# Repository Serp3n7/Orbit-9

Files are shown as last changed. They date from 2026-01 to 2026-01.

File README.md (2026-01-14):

# Orbit-9
**The Ultimate Macro-Controller for Developers & Designers**

  

---

## ⚡ Overview
**Orbit-9** is a workflow accelerator designed to replace repetitive keystrokes with single-tap efficiency. It combines a 3x3 mechanical grid with analog rotary control and a real-time OLED dashboard.

Whether you are snapping windows to multitask, controlling your media, or zooming through CAD models, Orbit-9 adapts to your workflow instantly.

## 💎 Key Features
* **Adaptive Intelligence:** 3 distinct layers (Navigation, Media, Design) that switch instantly via the encoder button.
* **Visual Feedback:** OLED display confirms your active mode and knob function.
* **Analog Control:** Precision rotary encoder for Volume, Brightness, and Zoom.
* **Window Management:** Dedicated layer for snapping windows and managing virtual desktops.
* **Developer Ready:** Native macros for VS Code, Git, and CAD tools.

---

## 🎛️ Workflow Modes

### 1. Navigator Mode (Default)
*The Multitasking Command Center.*
* **Knob:** `Volume Control`
* **Row 1:** `Desktop Left` • `Task View` • `Desktop Right`
* **Row 2:** `Snap Left` • `Maximize` • `Snap Right`
* **Row 3:** `Alt-Tab` • `Minimize` • `Screenshot`
* **Best For:** Managing multiple windows, splitting screens, and organizing your workspace.

### 2. Media Studio Mode
*The Entertainment Layer.*
* **Knob:** `Screen Brightness`
* **Keys:** Play, Pause, Next, Mute
* **Best For:** Spotify, YouTube, Background music control.

### 3. Design & Dev Mode (Pro)
*The Power User Suite.*
* **Knob:** `Zoom / Scroll` (Ctrl + Wheel)
* **Top Row:** `Undo` • `Copy` • `Paste`
* **Mid Row:** `Toggle Sidebar` • `Save` • `Command Palette`
* **Bot Row:** `Fit View (F6)` • `Format Code` • `Alt-Tab`

---

## 🛠️ Technical Specifications
| Spec | Detail |
| :--- | :--- |
| **Microcontroller** | Seeed Studio XIAO RP2040 |
| **Switch Matrix** | 3x3 (9 Keys) with Kailh Hotswap Sockets |
| **Display** | 0.96" OLED (SSD1306) |
| **Input Device** | EC11 Rotary Encoder |
| **Firmware** | KMK (CircuitPython) |

---

## 🚀 Quick Start
1.  **Flash:** Drag `CircuitPython.uf2` to the `RPI-RP2` drive.
2.  **Install:** Copy the `kmk` library folder to the `CIRCUITPY` drive.
3.  **Deploy:** Copy the `code.py` from this repo to the drive.
4.  **Use:** Click the knob to cycle modes.

---

## 🔌 Pinout Reference (Rev 1.0)
* **OLED:** `D4` (SDA), `D5` (SCL)
* **Encoder:** `D0`, `D1` (Rotation), `D10` (Switch)
* **Matrix Cols:** `D2`, `D3`, `D6`
* **Matrix Rows:** `D7`, `D8`, `D9`

---

## 📦 Bill of Materials
* 1x Seeed XIAO RP2040
* 1x Orbit-9 PCB
* 9x Kailh MX Hotswap Sockets
* 9x 1N4148 Diodes
* 1x EC11 Rotary Encoder
* 1x SSD1306 OLED Display
* 9x Mechanical Switches & Keycaps

---

## 📄 License
**Orbit-9** is Open Source Hardware.
* **Firmware:** MIT License
* **Hardware Design:** CERN-OHL-W

*Designed with ❤️ by [Sumit Patil]*

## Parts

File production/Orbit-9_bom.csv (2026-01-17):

Designator | Footprint | Quantity | Value | LCSC Part #
D1, D10, D2, D3, D4, D5, D6, D7, D8, D9 | Diode_SOD-123 | 10 | ~
H1, H2, H3, H4 | MountingHole_2.2mm_M2_DIN965_Pad | 4 | ~
J1 | PinSocket_1x04_P2.54mm_Vertical | 1 | Conn_01x04
R1, R2 | 0805 | 2 | R
S1, S2, S3, S4, S5, S6, S7, S8, S9 | Hotswap_MX_1.00u | 9 | ~
SW1 | RotaryEncoder_Alps_EC11E-Switch_Vertical_H20mm | 1 | RotaryEncoder_Switch
U1 | Seeed_XIAO_RP2040 | 1 | MCU_Seeed_XIAO_RP2040

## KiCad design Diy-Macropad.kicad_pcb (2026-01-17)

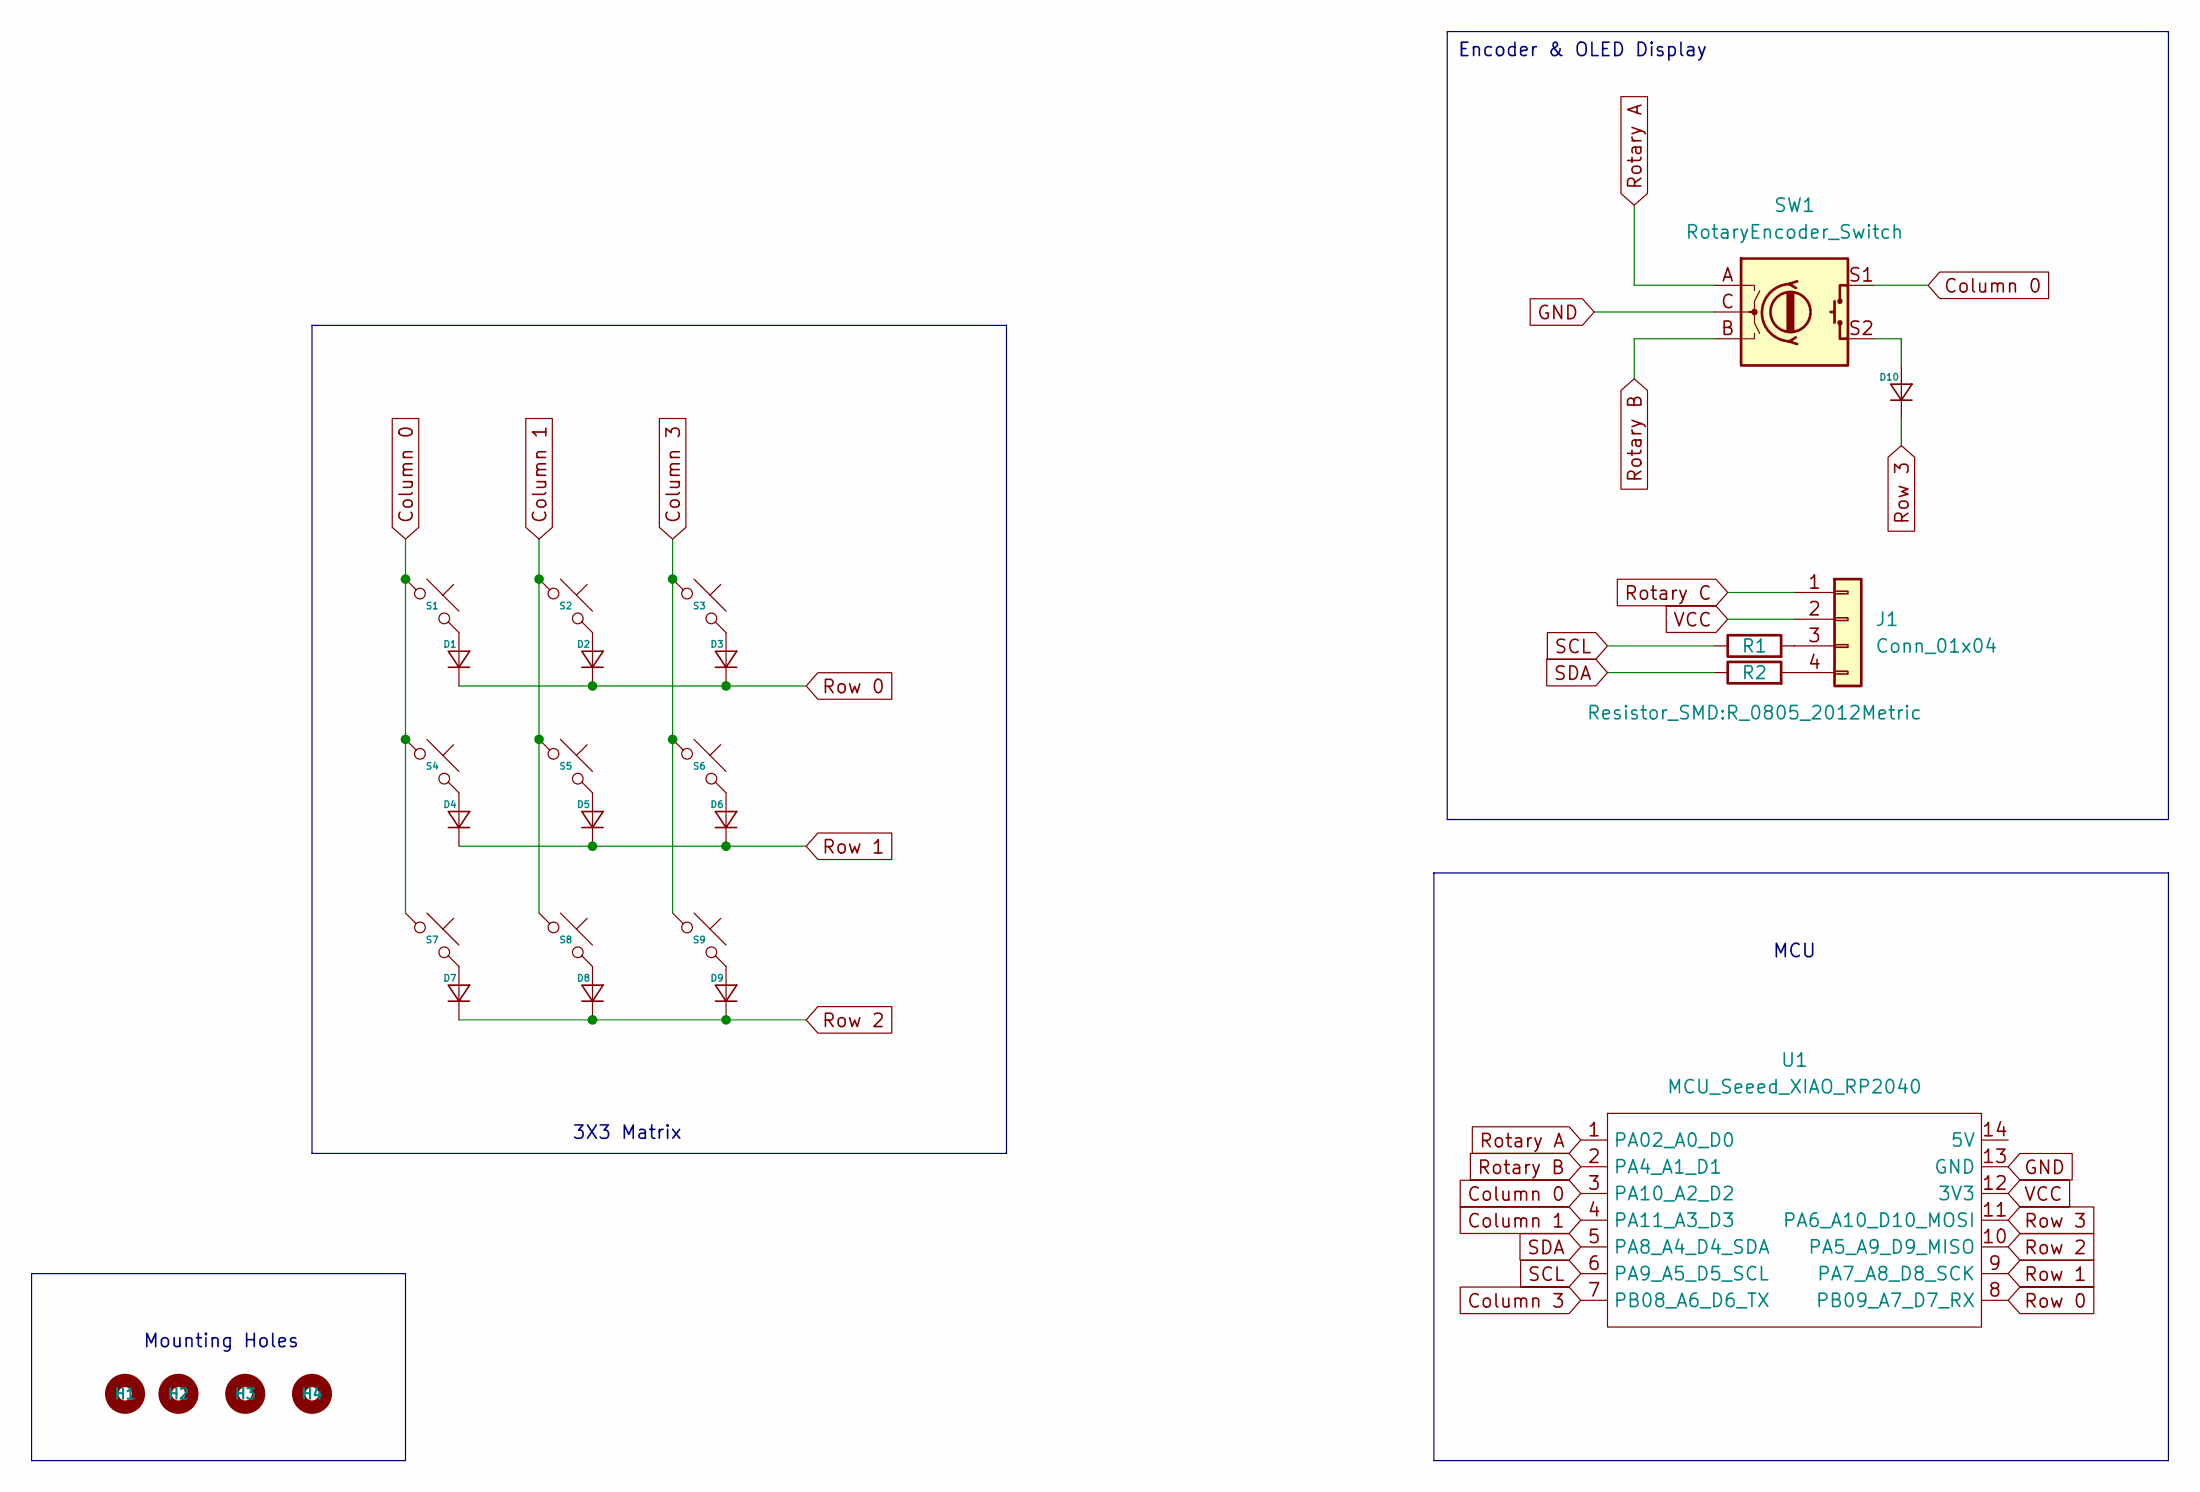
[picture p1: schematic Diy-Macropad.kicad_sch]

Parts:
D1, D2, D3, D4, D5, D6, D7, D8, D9, D10: Diode_SOD-123
H1, H2, H3, H4: MountingHole_2.2mm_M2_DIN965_Pad
J1: Conn_01x04; PinSocket_1x04_P2.54mm_Vertical
R1, R2: R; R_0805_2012Metric
S1, S2, S3, S4, S5, S6, S7, S8, S9: Hotswap_MX_1.00u
SW1: RotaryEncoder_Switch; RotaryEncoder_Alps_EC11E-Switch_Vertical_H20mm
U1: MCU_Seeed_XIAO_RP2040; Seeed_XIAO_RP2040

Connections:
Column 0: S1.1, S4.1, S7.1, SW1.S1, U1.3 (PA10_A2_D2)
Column 1: S2.1, S5.1, S8.1, U1.4 (PA11_A3_D3)
Column 3: S3.1, S6.1, S9.1, U1.7 (PB08_A6_D6_TX)
GND: SW1.C, U1.13 (GND)
unnamed: D1.2 (A), S1.2
unnamed: D2.2 (A), S2.2
unnamed: D3.2 (A), S3.2
unnamed: D4.2 (A), S4.2
unnamed: D5.2 (A), S5.2
unnamed: D6.2 (A), S6.2
unnamed: D7.2 (A), S7.2
unnamed: D8.2 (A), S8.2
unnamed: D9.2 (A), S9.2
unnamed: D10.2 (A), SW1.S2
unnamed: J1.3, R1.2
unnamed: J1.4, R2.2
Rotary A: SW1.A, U1.1 (PA02_A0_D0)
Rotary B: SW1.B, U1.2 (PA4_A1_D1)
Rotary C: J1.1
Row 0: D1.1 (K), D2.1 (K), D3.1 (K), U1.8 (PB09_A7_D7_RX)
Row 1: D4.1 (K), D5.1 (K), D6.1 (K), U1.9 (PA7_A8_D8_SCK)
Row 2: D7.1 (K), D8.1 (K), D9.1 (K), U1.10 (PA5_A9_D9_MISO)
Row 3: D10.1 (K), U1.11 (PA6_A10_D10_MOSI)
SCL: R1.1, U1.6 (PA9_A5_D5_SCL)
SDA: R2.1, U1.5 (PA8_A4_D4_SDA)
VCC: J1.2, U1.12 (3V3)

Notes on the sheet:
3X3 Matrix
Mounting Holes
MCU
Encoder & OLED Display

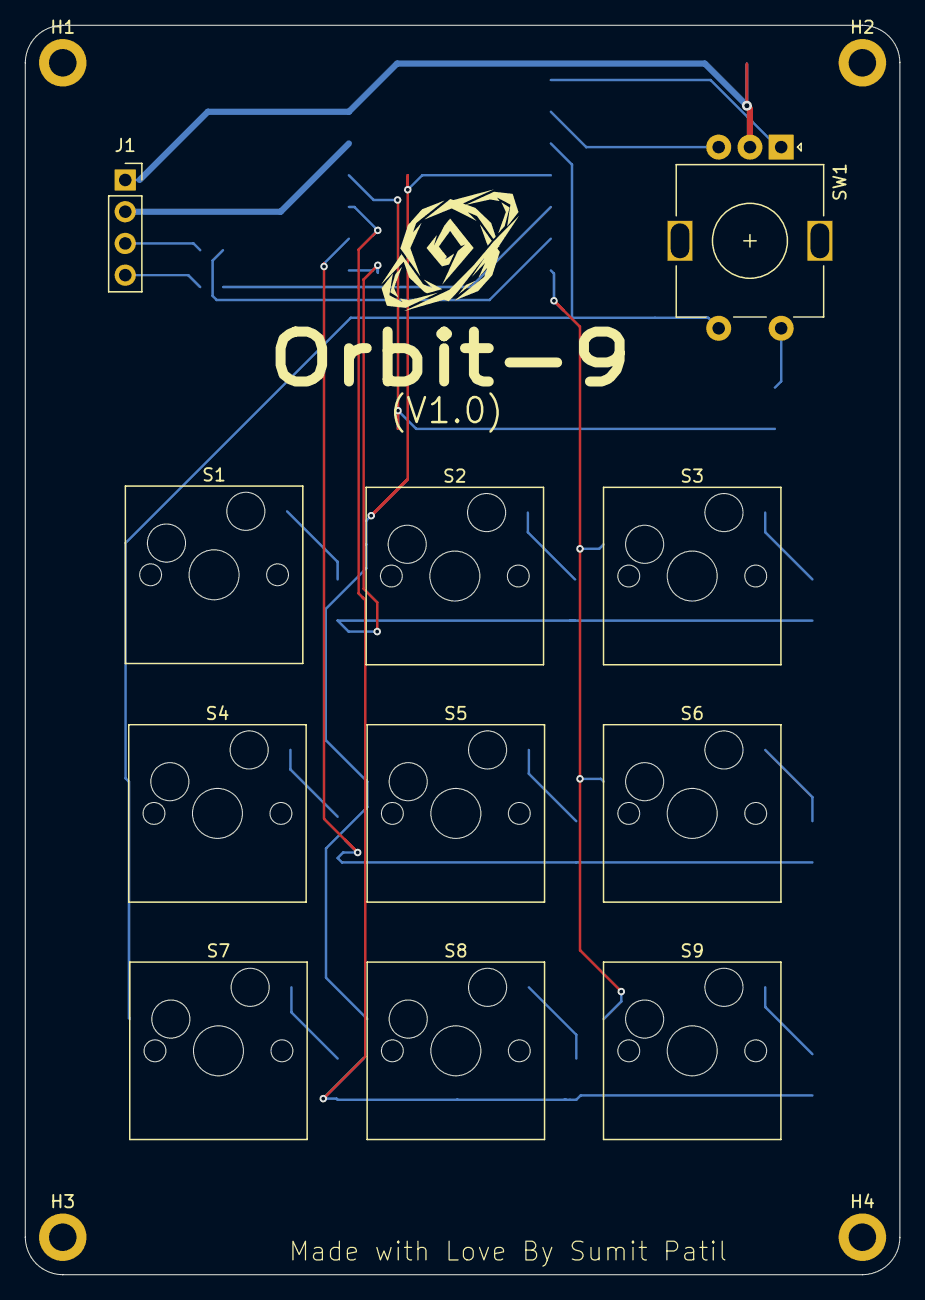
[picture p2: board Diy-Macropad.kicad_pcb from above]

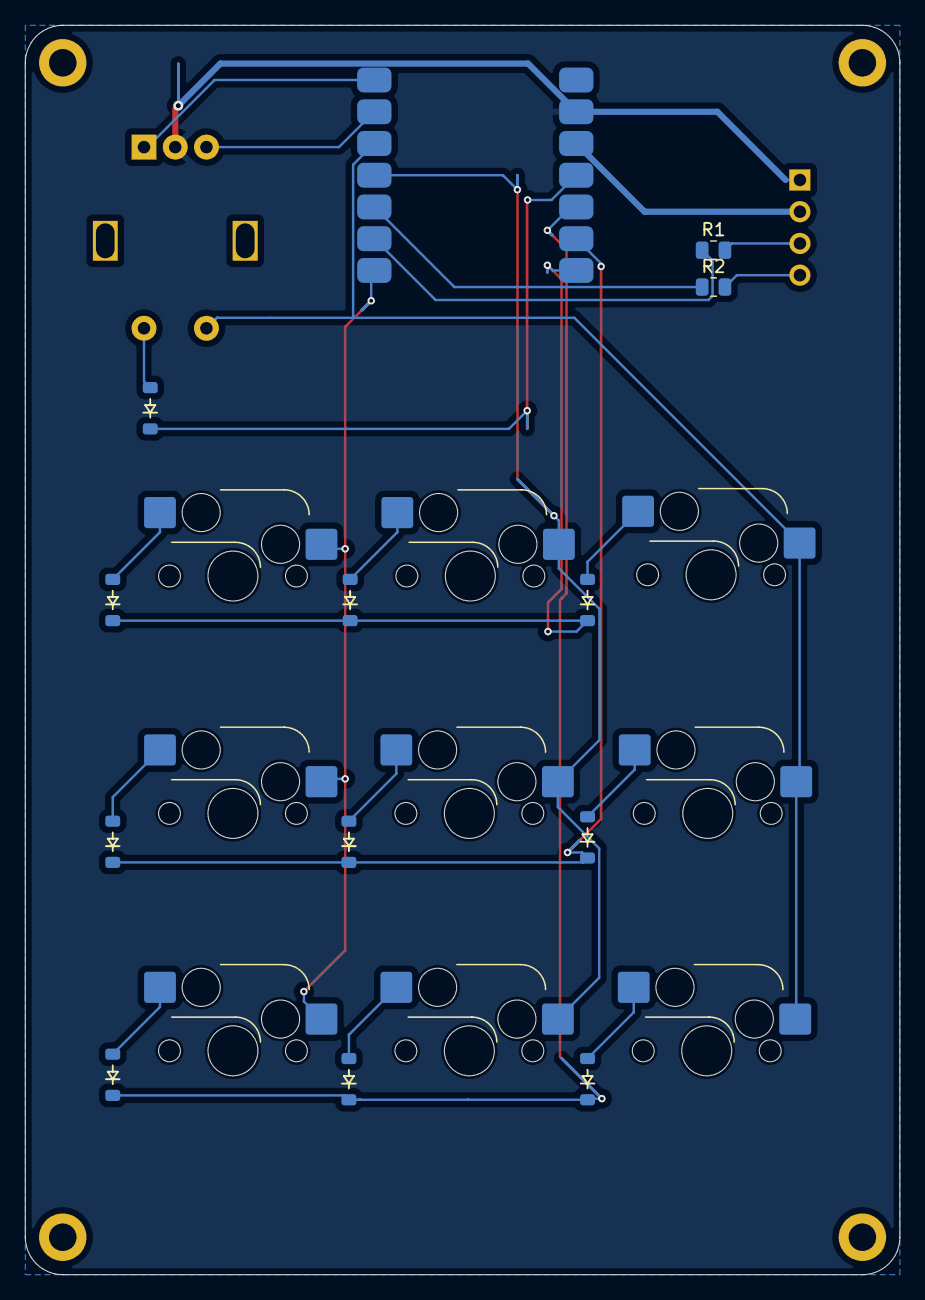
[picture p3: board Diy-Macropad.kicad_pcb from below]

Board: 2 copper layers, 70.0 x 100.0 mm, 28 parts (13 on the bottom side), 25 nets.

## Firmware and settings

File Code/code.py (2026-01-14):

import board
import busio
import displayio
import terminalio
from adafruit_display_text import label
import adafruit_ssd1306

from kmk.kmk_keyboard import KMKKeyboard
from kmk.keys import KC
from kmk.scanners import DiodeOrientation
from kmk.modules.encoder import EncoderHandler
from kmk.modules.layers import Layers
from kmk.extensions.media_keys import MediaKeys
from kmk.handlers.sequences import send_string
from kmk.extensions.pegasus_oled_ssd1306 import PegasusOLED

keyboard = KMKKeyboard()

# --- 1. HARDWARE PINOUT ---
keyboard.col_pins = (board.D2, board.D3, board.D6)
keyboard.row_pins = (board.D7, board.D8, board.D9, board.D10)
keyboard.diode_orientation = DiodeOrientation.COL2ROW

# --- 2. ENCODER SETUP ---
encoder_handler = EncoderHandler()
keyboard.modules.append(encoder_handler)
encoder_handler.pins = ((board.D0, board.D1, None, False),)

# --- 3. OLED UI SETUP ---
i2c_bus = busio.I2C(board.D5, board.D4) 

class OrbitOLED(PegasusOLED):
    def render(self):
        layer = keyboard.active_layers[0]
        if layer == 0:
            text = "NAVIGATE\n--------\nVol Ctrl"
        elif layer == 1:
            text = "MEDIA\n--------\nBrightns"
        elif layer == 2:
            text = "DESIGN\n--------\nZoom/Scr"
        else:
            text = "Orbit-9"
        self.set_text(text, 0, 0)

oled_ext = OrbitOLED(i2c_bus)
keyboard.extensions.append(oled_ext)

# --- 4. MODULES & MACROS ---
layers = Layers()
keyboard.modules.append(layers)
keyboard.extensions.append(MediaKeys())

def code_format(): keyboard.tap_key(KC.LSFT(KC.LALT(KC.F)))

# Layer Shifters
TO_BASE = KC.TO(0)
TO_MEDIA = KC.TO(1)
TO_DESIGN = KC.TO(2)

# --- 5. KEYMAPS ---

# LAYER 0: WINDOW NAVIGATOR (Productivity Base)
# Knob: Volume (Always useful)
L0_MAP = [
    # Row 1: Virtual Desktops & Task View
    [ KC.LCTL(KC.LGUI(KC.LEFT)), KC.LGUI(KC.TAB),     KC.LCTL(KC.LGUI(KC.RIGHT)) ], 
    # (Desktop Left),            (Task View),         (Desktop Right)

    # Row 2: Window Snapping (Split Screen)
    [ KC.LGUI(KC.LEFT),          KC.LGUI(KC.UP),      KC.LGUI(KC.RIGHT)          ],
    # (Snap Left),               (Maximize),          (Snap Right)

    # Row 3: App Switching & Minimizing
    [ KC.LALT(KC.TAB),           KC.LGUI(KC.DOWN),    KC.LGUI(KC.LSFT(KC.S))     ],
    # (Alt-Tab),                 (Minimize/Restore),  (Screenshot Tool)

    # Row 4: Encoder Switch -> Go to Media
    [ TO_MEDIA,                  KC.NO,               KC.NO                      ]  
]
L0_ENC = ( (KC.VOLU, KC.VOLD, None), ) 

# LAYER 1: MEDIA
L1_MAP = [
    [ KC.MPRV, KC.MPLY, KC.MNXT ],
    [ KC.MUTE, KC.VOLD, KC.VOLU ],
    [ KC.NO,   KC.NO,   KC.NO   ],
    [ TO_DESIGN, KC.NO, KC.NO   ]  # Switch click -> Go to Design Layer
]
L1_ENC = ( (KC.BRIU, KC.BRID, None), )

# LAYER 2: DESIGN (Fusion 360 / VS Code)
L2_MAP = [
    [ KC.LCTL(KC.Z),  KC.LCTL(KC.C),   KC.LCTL(KC.V)       ], # Undo, Copy, Paste
    [ KC.LCTL(KC.B),  KC.LCTL(KC.S),   KC.LCTL(KC.LSFT(KC.P)) ], # Sidebar, Save, Cmd Palette
    [ KC.F6,          KC.LSFT(KC.LALT(KC.F)), KC.LALT(KC.TAB) ], # Fit View, Format, Alt-Tab
    [ TO_BASE,        KC.NO,           KC.NO               ] # Back to Navigator
]
L2_ENC = ( (KC.LCTL(KC.MW_UP), KC.LCTL(KC.MW_DN), None), )

# --- APPLY ---
keyboard.keymap = [
    [key for row in L0_MAP for key in row],
    [key for row in L1_MAP for key in row],
    [key for row in L2_MAP for key in row]
]
encoder_handler.map = [L0_ENC, L1_ENC, L2_ENC]

if __name__ == '__main__':
    keyboard.go()

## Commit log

2026-01-14 added all necessary files
    [Diy-Macropad.kicad_pcb, Diy-Macropad.kicad_sch, Orbit-9_bom.csv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]
2026-01-17 added copper ground
    [Diy-Macropad.kicad_pcb, Diy-Macropad.kicad_sch, Orbit-9_bom.csv]
